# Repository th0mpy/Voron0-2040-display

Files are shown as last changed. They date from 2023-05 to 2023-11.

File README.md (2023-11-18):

# Voron0-2040-display
RP2040 port of the Voron0 display

If you are in the US and want an already built display, you can find them on my Etsy shop here:
https://www.etsy.com/tArrayEngineering/listing/1458617388/voron0-13-display-based-on-the-rp2040

For those of you in the EU, you can find them on Lab4450:
https://lab4450.com/product/voron-v02-rp2040-display/

I created this port in order to give another option when it comes to the Voron0 display. Additionally it makes use of the easily available RP2040 IC for ease of modificaion and implementation. The files in this github are everything you should need, if you wanted to make your own or if you have any questions about the details of the device.

The display includes both a USB-C connector and 4-pin header. This makes installation a little cleaner, allowing you to use standard dupont connectors versus longer USB connectors.

*** Only one data connector can be used. Do not attempt to plug anything into the USB connector while the pin header is in use.

To configure this display, you can use use the following parameters:

```
[mcu rp2040]
serial: /dev/serial/by-id/<modify this value to match your system> # Details to be found in https://github.com/th0mpy/Voron0-2040-display
restart_method: command

[display]
lcd_type: sh1106
i2c_mcu: rp2040
i2c_bus: i2c0a
vcomh: 31
x_offset: 2
encoder_pins: ^rp2040:gpio7, ^rp2040:gpio6
click_pin: ^!rp2040:gpio8
kill_pin: ^!rp2040:gpio5

[neopixel rp2040]
pin: rp2040:gpio16
chain_count: 1
color_order: GRB
initial_RED: .6
initial_GREEN: 0
initial_BLUE: .75
```

One method to find the serial port used by the display is to simply call `ls /dev/serial/by-id` and look for a device which will be called something like usb-Klipper_rp2040_E6625495537C5221-if00 (the device will show up after it is plugged in).

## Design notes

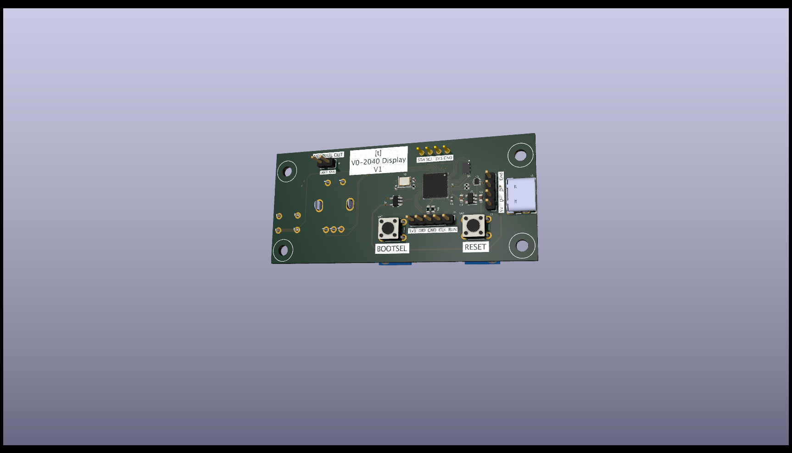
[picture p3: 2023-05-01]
Images/V0_Display-back.png

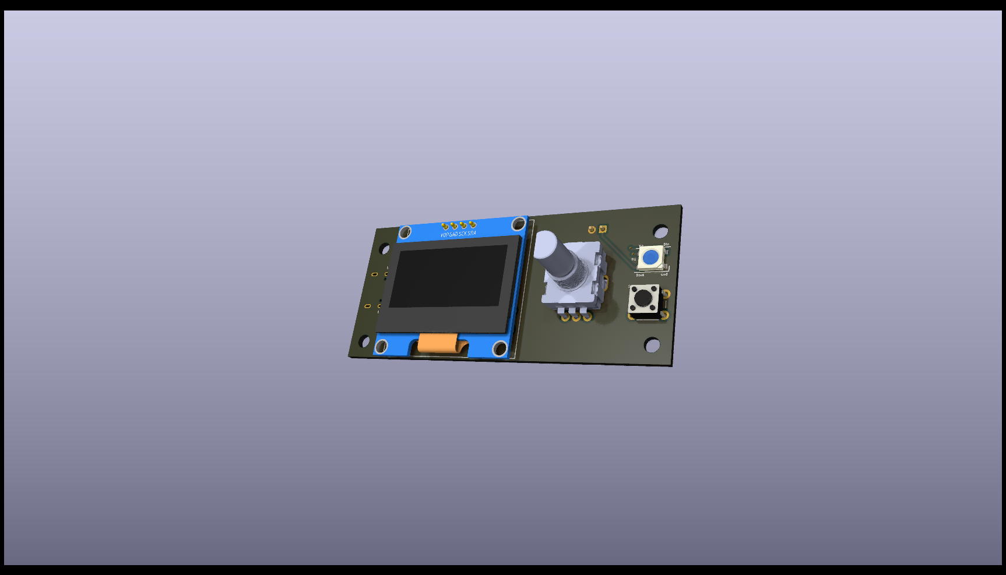
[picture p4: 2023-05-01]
Images/V0_Display-front.png

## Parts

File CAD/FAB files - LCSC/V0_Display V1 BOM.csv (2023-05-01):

Comment | Designator | Footprint | LCSC
4.7uF | C1,C2 | Capacitor_SMD:C_0603_1608Metric | C109456
27pf | C3,C4 | Capacitor_SMD:C_0402_1005Metric | C541471
0.1uf | C5,C6,C7,C8,C10,C11,C12,C13,C14,C15,C16,C17 | Capacitor_SMD:C_0402_1005Metric | C129131
1uf | C9 | Capacitor_SMD:C_0402_1005Metric | C106254
WS2812B | D1 | V0-Display:LED_WS2812B_PLCC4_5.0x5.0mm_P3.2mm | C2761795
USB-TYPE-C-018 | J4 | USB4105-GF-A:GCT_USB4105-GF-A | C2927038
120R 100MHZ | L1 | Inductor_SMD:L_0402_1005Metric | C107331
1K | R1 | Resistor_SMD:R_0603_1608Metric | C22548
1k | R2 | Resistor_SMD:R_0402_1005Metric | C852624
10k | R3,R4 | Resistor_SMD:R_0603_1608Metric | C98220
5.1K | R5,R6 | Resistor_SMD:R_0402_1005Metric | C105873
AP2127K-3.3 | U1 | V0-Display:SOT-23-5 | C156285
USBLC6-2P6 | U2 | Package_TO_SOT_SMD:SOT-666 | C2827693
74LVC1G17 | U3 | V0-Display:SOT-753 | C6076
W25Q16JVUXIQ_TR | U4 | W25Q16JVUXIQ_TR:IC_W25Q16JVUXIQ_TR | C2843335
RP2040 | U5 | V0-Display:RP2040-QFN-56 | C2040
12Mhz | Y1 | Crystal:Crystal_SMD_3225-4Pin_3.2x2.5mm | C403945

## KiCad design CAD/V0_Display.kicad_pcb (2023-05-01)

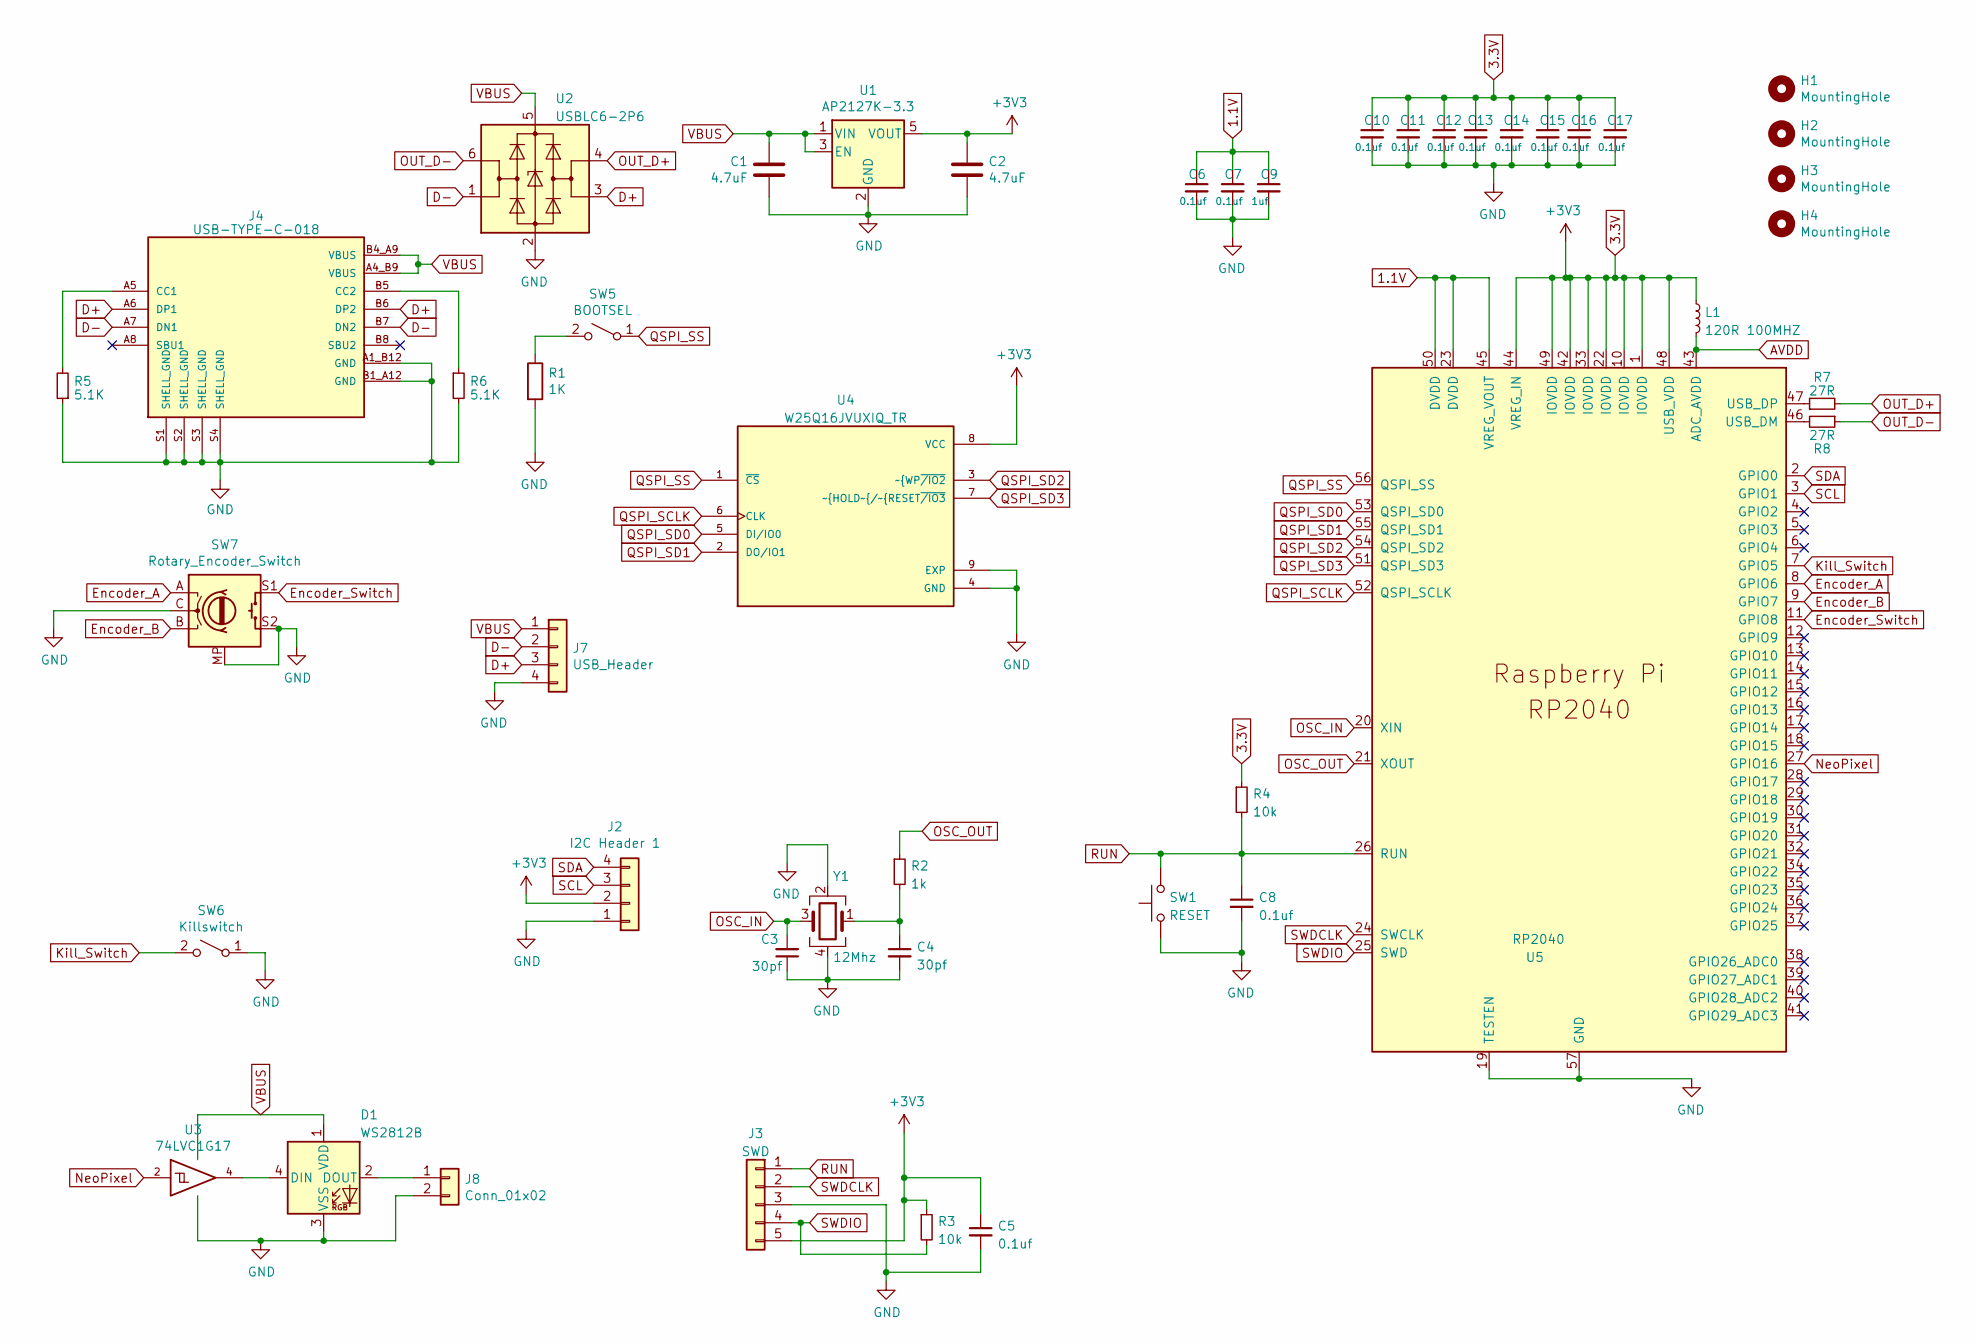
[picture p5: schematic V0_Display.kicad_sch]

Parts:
C1, C2: 4.7uF; C_0603_1608Metric; LCSC C326580
C3, C4: 30pf; C_0402_1005Metric; LCSC C526980
C5, C6, C7, C8, C10, C11, C12, C13, C14, C15, C16, C17: 0.1uf; C_0402_1005Metric; LCSC C129131
C9: 1uf; C_0402_1005Metric; LCSC C106254
D1: WS2812B; LED_WS2812B_PLCC4_5.0x5.0mm_P3.2mm; LCSC C114586
H1, H2, H3, H4: MountingHole; MountingHole_3.2mm_M3
J2: I2C Header 1; 1pt3in_OLED
J3: SWD; PinHeader_1x05_P2.54mm_Vertical
J4: USB-TYPE-C-018; GCT_USB4105-GF-A; LCSC C2927038
J7: USB_Header; PinHeader_1x04_P2.54mm_Vertical
J8: Conn_01x02; PinHeader_1x02_P2.54mm_Vertical
L1: 120R 100MHZ; L_0402_1005Metric; LCSC C107331
R1: 1K; R_0603_1608Metric; LCSC C4295595
R2: 1k; R_0402_1005Metric; LCSC C852624
R3, R4: 10k; R_0603_1608Metric; LCSC C2139679
R5, R6: 5.1K; R_0402_1005Metric; LCSC C105873
R7, R8: 27R; R_0402_1005Metric; LCSC C137890
SW1: RESET; SW_PUSH_6mm; MPN MJTP1230
SW5: BOOTSEL; SW_PUSH_6mm; MPN MJTP1230
SW6: Killswitch; SW_PUSH_6mm; MPN MJTP1230
SW7: Rotary_Encoder_Switch; EN11_Encoder; MPN EN11-HSB1AF15
U1: AP2127K-3.3; SOT-23-5; LCSC C156285
U2: USBLC6-2P6; SOT-666; LCSC C2827693
U3: 74LVC1G17; SOT-753; LCSC C6076
U4: W25Q16JVUXIQ_TR; IC_W25Q16JVUXIQ_TR; LCSC C2843335
U5: RP2040; RP2040-QFN-56; LCSC C2040
Y1: 12Mhz; Crystal_SMD_3225-4Pin_3.2x2.5mm; LCSC C133334

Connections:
1.1V: C6.1, C7.1, C9.1, U5.23 (DVDD), U5.45 (VREG_VOUT), U5.50 (DVDD)
3.3V: C2.1, C5.1, C10.1, C11.1, C12.1, C13.1, C14.1, C15.1, C16.1, C17.1, J2.2, J3.5, L1.1, R3.1, R4.1, U1.5 (VOUT), U4.8 (VCC), U5.1 (IOVDD), U5.10 (IOVDD), U5.22 (IOVDD), U5.33 (IOVDD), U5.42 (IOVDD), U5.44 (VREG_IN), U5.48 (USB_VDD), U5.49 (IOVDD)
AVDD: L1.2, U5.43 (ADC_AVDD)
D+: J4.A6 (DP1), J4.B6 (DP2), J7.3, U2.3 (I/O2)
D-: J4.A7 (DN1), J4.B7 (DN2), J7.2, U2.1 (I/O1)
Encoder_A: SW7.A, U5.8 (GPIO6)
Encoder_B: SW7.B, U5.9 (GPIO7)
Encoder_Switch: SW7.S1, U5.11 (GPIO8)
GND: C1.2, C2.2, C3.1, C4.2, C5.2, C6.2, C7.2, C8.2, C9.2, C10.2, C11.2, C12.2, C13.2, C14.2, C15.2, C16.2, C17.2, D1.3 (VSS), J2.1, J3.3, J4.A1_B12 (GND), J4.B1_A12 (GND), J4.S1 (SHELL_GND), J4.S2 (SHELL_GND), J4.S3 (SHELL_GND), J4.S4 (SHELL_GND), J7.4, J8.2, R1.2, R5.1, R6.2, SW1.1, SW6.1 (A), SW7.C, SW7.MP, SW7.S2, U1.2 (GND), U2.2 (GND), U3.3 (GND), U4.4 (GND), U4.9 (EXP), U5.19 (TESTEN), U5.57 (GND), Y1.2, Y1.4
Kill_Switch: SW6.2 (B), U5.7 (GPIO5)
NeoPixel: U3.2, U5.27 (GPIO16)
unnamed: C4.1, R2.2, Y1.1
unnamed: D1.4 (DIN), U3.4
unnamed: D1.2 (DOUT), J8.1
unnamed: J4.A5 (CC1), R5.2
unnamed: J4.B5 (CC2), R6.1
unnamed: R1.1, SW5.2 (B)
unnamed: R8.2, U5.46 (USB_DM)
unnamed: R7.1, U5.47 (USB_DP)
OSC_IN: C3.2, U5.20 (XIN), Y1.3
OSC_OUT: R2.1, U5.21 (XOUT)
OUT_D+: R7.2, U2.4 (I/O2)
OUT_D-: R8.1, U2.6 (I/O1)
QSPI_SCLK: U4.6 (CLK), U5.52 (QSPI_SCLK)
QSPI_SD0: U4.5 (DI/IO0), U5.53 (QSPI_SD0)
QSPI_SD1: U4.2 (DO/IO1), U5.55 (QSPI_SD1)
QSPI_SD2: U4.3 (~WP~{/IO2), U5.54 (QSPI_SD2)
QSPI_SD3: U4.7 (~HOLD~{/~{RESET~{/IO3), U5.51 (QSPI_SD3)
QSPI_SS: SW5.1 (A), U4.1 (~CS), U5.56 (QSPI_SS)
RUN: C8.1, J3.1, R4.2, SW1.2, U5.26 (RUN)
SCL: J2.3, U5.3 (GPIO1)
SDA: J2.4, U5.2 (GPIO0)
SWDCLK: J3.2, U5.24 (SWCLK)
SWDIO: J3.4, R3.2, U5.25 (SWD)
VBUS: C1.1, D1.1 (VDD), J4.A4_B9 (VBUS), J4.B4_A9 (VBUS), J7.1, U1.1 (VIN), U1.3 (EN), U2.5 (VBUS), U3.5 (VCC)

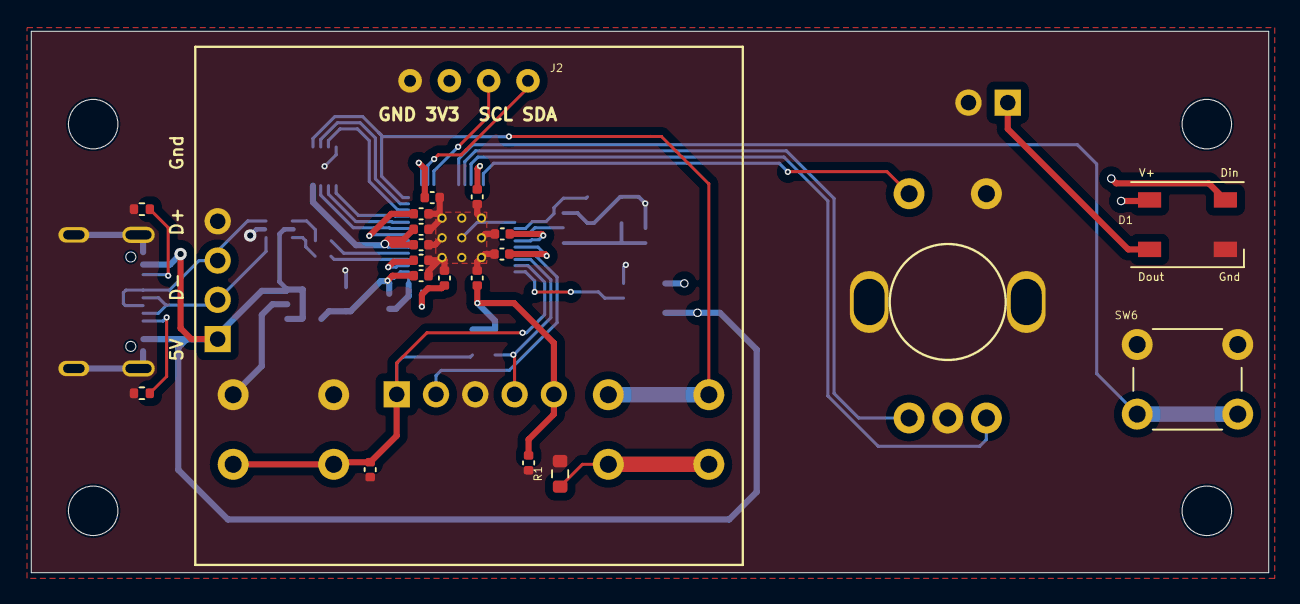
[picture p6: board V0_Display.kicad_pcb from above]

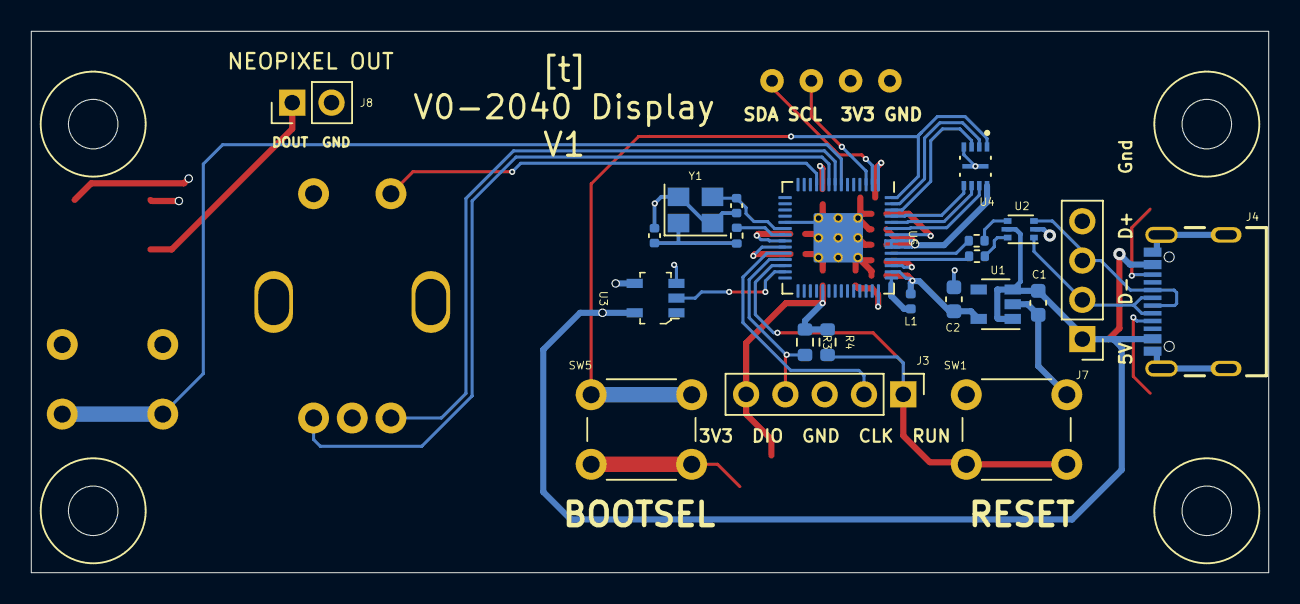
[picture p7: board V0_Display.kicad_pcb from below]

Board: 4 copper layers, 80.0 x 35.0 mm, 46 parts (22 on the bottom side), 35 nets.

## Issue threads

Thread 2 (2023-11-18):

Screen doesnt turn on when printer powered on

pmiller8, 2023-11-18:
Screen purchased from fabreeko. Troubleshot and have to reflash screen after each power cycle on printer to get screen to turn on. Running klipper v0.12.0-1-g74473322. Request flashing instructions if able.

th0mpy, 2023-11-18:
If you bought from Frabreeko it's not my original design. Standard RP2040 flashing instructions would apply though.

th0mpy, 2023-11-18:
That said we can try and see if there's anything obvious. How are you connecting to your Raspberry Pi (pin header or usb connector)? Secondly what does your config look like for defining the screen?

pmiller8, 2023-11-18:
I understand. Sorry for the wrong post. Connected via usb only. Config is copied from this github.

th0mpy, 2023-11-18:
To be fair the OG design is mine so I'd be interested in finding out what the issue is. I'm not sure, however, who manufactured and how it was done. So I can't really comment on the build quality.

th0mpy, 2023-11-18:
When you do flash the firmware, what options have you selected in menuconfig? Can you send a screenshot?

th0mpy, 2023-11-18:
Also, can you paste in your config? I just re-read your original question and, it's true the display does not come on when powered up, it takes a few seconds. It'd be good to just verify the whole config.

th0mpy, 2023-11-18:
One more thing... After rebooting the SBC can you run a lsusb on the raspberry pi and paste the output here?

pmiller8, 2023-11-18:
Im not home to administer to the machine.  But from a cold boot and lsusb, the output is
`Bus 002 Device 001: ID 1d6b:0003 Linux Foundation 3.0 root hub
Bus 001 Device 004: ID 1d50:614e OpenMoko, Inc. rp2040
Bus 001 Device 003: ID 1d50:614e OpenMoko, Inc. rp2040
Bus 001 Device 002: ID 2109:3431 VIA Labs, Inc. Hub
Bus 001 Device 001: ID 1d6b:0002 Linux Foundation 2.0 root hub`

If i hold the bootsel button when plugging it in, i can actually detect it with lsusb.

th0mpy, 2023-11-18:
Well.... I assume that you are running a SKR Pico board, in which case the two items listed in the lsusb:
Bus 001 Device 004: ID 1d50:614e OpenMoko, Inc. rp2040
Bus 001 Device 003: ID 1d50:614e OpenMoko, Inc. rp2040

One is your SKR board and the other is the Display.

Then, If you do:
ls /dev/serial/by-id/* what do you see there? Again, assuming you have a SKR Pico there will be two entries, one for the display and the other for the pico.

If I were to guess, it's probably working fine but the firmware is not correct.

Try the attached firmware and see if you have better results.
[RP2040DisplayFirmware.zip](https://github.com/th0mpy/Voron0-2040-display/files/13398891/RP2040DisplayFirmware.zip)

pmiller8, 2023-11-18:
Will do!  Thanks for the help.  Ill do this tomorrow night and report back here.

pmiller8, 2023-11-19:
uploaded the firmware you provided.  below is the error i receive.

Klipper reports: ERROR

MCU Protocol error

This is frequently caused by running an older version of the
firmware on the MCU(s). Fix by recompiling and flashing the
firmware.

Your Klipper version is: v0.12.0-1-g74473322
MCU(s) which should be updated:
mcu: Current version v0.11.0-311-g9e765dae
umb: Current version v0.11.0-311-g9e765dae
rpi: Current version v0.11.0-311-g9e765dae
rp2040: Current version v0.11.0-200-g7511151a
Up-to-date MCU(s):
<none>

Once the underlying issue is corrected, use the "RESTART"
command to reload the config and restart the host software.

mcu 'rp2040': Unable to encode: config_i2c

i take it my mcu and umb are out of date?

pmiller8, 2023-11-19:
Ive update my klipper versions on the mcu and umb.  from klippy.log, on reboot, i get this error:

mcu 'rp2040': Unable to open serial port: [Errno 2] could not open port /dev/serial/by-id/usb-Klipper_rp2040_E6625C05E7123D26-if00: [Errno 2] No such file or directory: '/dev/serial/by-id/usb-Klipper_rp2040_E6625C05E7123D26-if00'

th0mpy, 2023-11-19:
Can you double check and do an "ls /dev/serial/by-id/"

My firmware that I sent you is likely going to report back usb-Klipper_rp2040_V0-DISPLAY-if00 instead of what you have above.

Then just update the printer.cfg with that new value.

pmiller8, 2023-11-19:
so ive reflashed with your firmware and compiled my own.  when i flashed with yours, it shows up as:
usb-Klipper_rp2040_V0DISPLAY-if00

i put that into my .cfg and do a soft restart.  i now have a klipper version error.

MCU Protocol error

This is frequently caused by running an older version of the
firmware on the MCU(s). Fix by recompiling and flashing the
firmware.

Your Klipper version is: v0.12.0-1-g74473322
MCU(s) which should be updated:
display: Current version v0.11.0-200-g7511151a
Up-to-date MCU(s):
mcu: Current version v0.12.0-1-g74473322
umb: Current version v0.12.0-1-g74473322
rpi: Current version v0.12.0-1-g74473322

Once the underlying issue is corrected, use the "RESTART"
command to reload the config and restart the host software.

mcu 'display': Unable to encode: config_i2c

pmiller8, 2023-11-19:
can you please post the menuconfig settings your using so i can compile new firmware with klipper v0.12.0-1-g74473322?

th0mpy, 2023-11-19:
Here you are. Let me know if this helps.
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

You'll also want to go into "USB ids --->" and enter an ID

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

th0mpy, 2023-11-19:
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

pmiller8, 2023-11-20:
I tried with yours and built my own.  I tried another screen from fabreeko.  the klipper log keeps saying:

mcu 'rp2040': Unable to open serial port: [Errno 2] could not open port //dev/serial/by-id/usb-Klipper_rp2040_V0DISPLAY-if00: [Errno 2] No such file or directory: '//dev/serial/by-id/usb-Klipper_rp2040_V0DISPLAY-if00'

i think its my pi or a permisisons issue so im gonna wipe the card and start over.  ill report back if it keeps happening but at this point it has to be an error on my part.  thanks for the help!

th0mpy, 2023-11-20:
Permissions are entirely possible as well.

Without having the device in-hand I’m not sure what else to recommend. I ordered one from Fabreeko so I might be able to give more once I have it. Keep me posted.

Thanks,
Chris

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

pmiller8, 2023-11-21:
finally figured it out.  i was trying to install the firmware to sda1.   needed to be copied to just /dev/sda.

thanks for the help and sorry for the waste of time (cause it was my fault)

pmiller8, 2023-11-21:
below is the error im getting on a fresh install on the sd card.

mcu 'rp2040': Unable to open serial port: [Errno 2] could not open port /dev/serial/by-id/usb-Klipper_rp2040_V0DISPLAY-if00: [Errno 2] No such file or directory: '/dev/serial/by-id/usb-Klipper_rp2040_V0DISPLAY-if00'

th0mpy, 2023-11-21:
Can you confirm whether that path exists? It sounds like it may not be booting up into the program. One thing you can try is to plug it in, then hit reset on the board itself. Then check to see if that path exists. You can also check lsusb and or dmesg to see if it's trying to connect.

pmiller8, 2023-11-22:
Im pretty sure the display isnt flashing properly.   here's the dmesg:

[ 1057.758854] usb 1-1.1: new full-speed USB device number 10 using xhci_hcd
[ 1057.867394] usb 1-1.1: New USB device found, idVendor=1d50, idProduct=614e, bcdDevice= 1.00
[ 1057.867414] usb 1-1.1: New USB device strings: Mfr=1, Product=2, SerialNumber=3
[ 1057.867420] usb 1-1.1: Product: rp2040
[ 1057.867425] usb 1-1.1: Manufacturer: Klipper
[ 1057.867430] usb 1-1.1: SerialNumber: V0DISPLAY
[ 1057.873804] cdc_acm 1-1.1:1.0: ttyACM2: USB ACM device
[ 1062.480947] FAT-fs (sda1): FAT read failed (blocknr 1)
[ 1062.481667] FAT-fs (sda1): unable to read boot sector to mark fs as dirty
[ 1082.940433] usb 1-1.1: USB disconnect, device number 10

pmiller8, 2023-11-22:
I, FINALLY, solved it.

reading around, i found a post (somewhere) that directed me to change the 'Flash Chip' in menuconfig from "W25Q080 with CLKDIV 2" to "GENERIC_03H with CLKDIV4"

it appears to have fixed it as the screen comes on everytime i cycle power, is responsive, and shows up in terminal.  Thanks for the troublehsooting help along the way!   Please let me know why this fixed it!

th0mpy, 2023-11-22:
I think what happened here is the board was manufactured using old schematics. I'm in the process now of getting the folks at Voron to check it into their main hardware, which has some circuit changes. I think why this works is that it's causing a little bit of a delay in the startup routine of the chip, which combats any delay in the crystal from firing up to a stable signal. Early on I had this issue in another derivative that I was working on, and I fixed it by changing some of the circuit traces and adding a pullup on the run pin.

Again, that's just speculation. I ordered one from Fabreeko so I'll play with it a bit to determine what is going on with it.

I DO know that the latest version will be merged into the Voron github and it does not have this issue.
